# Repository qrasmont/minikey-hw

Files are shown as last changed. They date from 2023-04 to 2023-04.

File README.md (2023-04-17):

# Minikey

Mini is a macropad.

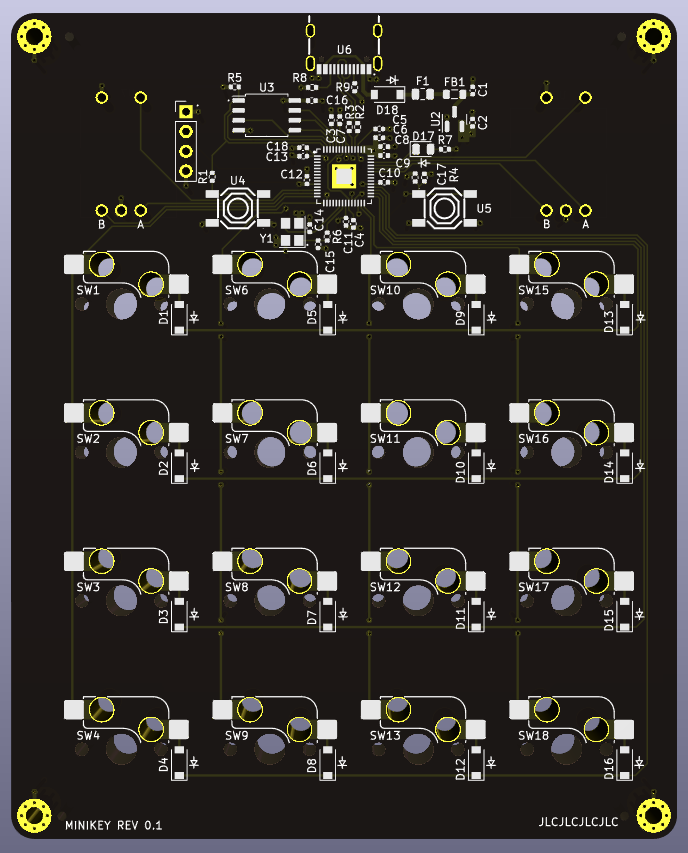
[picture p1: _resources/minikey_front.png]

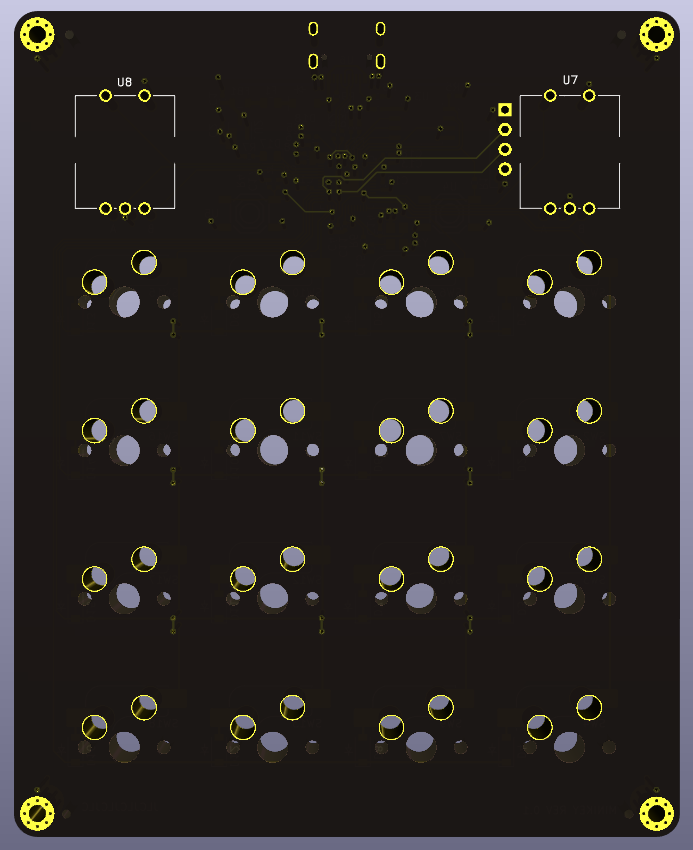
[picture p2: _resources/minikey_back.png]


## Rev 0.1




### Rev 0.1 Issues

Only related to the BOM.
- Button were not assembled
- R2,R3 are 27K instead of 27 Ohm.

# Characteristics

- 2 rotatry encoders
- 16 keys (Cherry MX, hot swappable)
- USB-C
- RP2040 MCU

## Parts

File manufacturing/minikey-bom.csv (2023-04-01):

Comment | Designator | Footprint | LCSC Part #
1u Unpolarized capacitor, small symbol | C1,C2,C5,C6 | C_0402_1005Metric | C52923
100n Unpolarized capacitor, small symbol | C3,C4,C7,C8,C9,C10,C11,C12,C13,C16,C17,C18 | C_0402_1005Metric | C307331
30p Unpolarized capacitor, small symbol | C14,C15 | C_0402_1005Metric | C1570
D Diode | D1,D2,D3,D4,D5,D6,D7,D8,D9,D10,D11,D12,D13,D14,D15,D16 | D_SOD-123 | C81598
LED Light emitting diode | D17 | LED_0805_2012Metric | C2297
B5819W SL 40V 600mV@1A 1A SOD-323 Schottky Barrier Diodes, SOD-323 | D18 | D_SOD-123 | C8598
TLC-PSMD050 Resettable fuse, polymeric positive temperature coefficient, small symbol | F1 | Fuse_0805_2012Metric | C261942
100@100MHz Ferrite bead, small symbol | FB1 | L_0805_2012Metric | C1015
1k Resistor, small symbol | R1,R6 | R_0402_1005Metric | C11702
27 Resistor, small symbol | R2,R3 | R_0402_1005Metric | C25771
10k Resistor, small symbol | R4,R5 | R_0402_1005Metric | C25744
1k5 Resistor, small symbol | R7 | R_0402_1005Metric | C25867
5k1 Resistor, small symbol | R8,R9 | R_0402_1005Metric | C25905
RP2040TR7 | U1 | QFN40P700X700X90-57N | C2040
XC6206PxxxMR Positive 60-250mA Low Dropout Regulator, Fixed Output, SOT-23 | U2 | SOT-23 | C5446
W25Q128JVS 128Mb Serial Flash Memory, Standard/Dual/Quad SPI, SOIC-8 | U3 | SOIC-8_5.23x5.23mm_P1.27mm | C97521
BOOT | U4 | tactile-switch | C318884
RESET | U5 | tactile-switch | C318884
TYPE-C-31-M-12 | U6 | simple-usb-c | C165948
PEC11R-4215F-S0024 | U7,U8 | PEC11R-4215F-S0024
12MHz Four pin crystal, GND on pins 2 and 4 | Y1 | Crystal_SMD_3225-4Pin_3.2x2.5mm | C9002

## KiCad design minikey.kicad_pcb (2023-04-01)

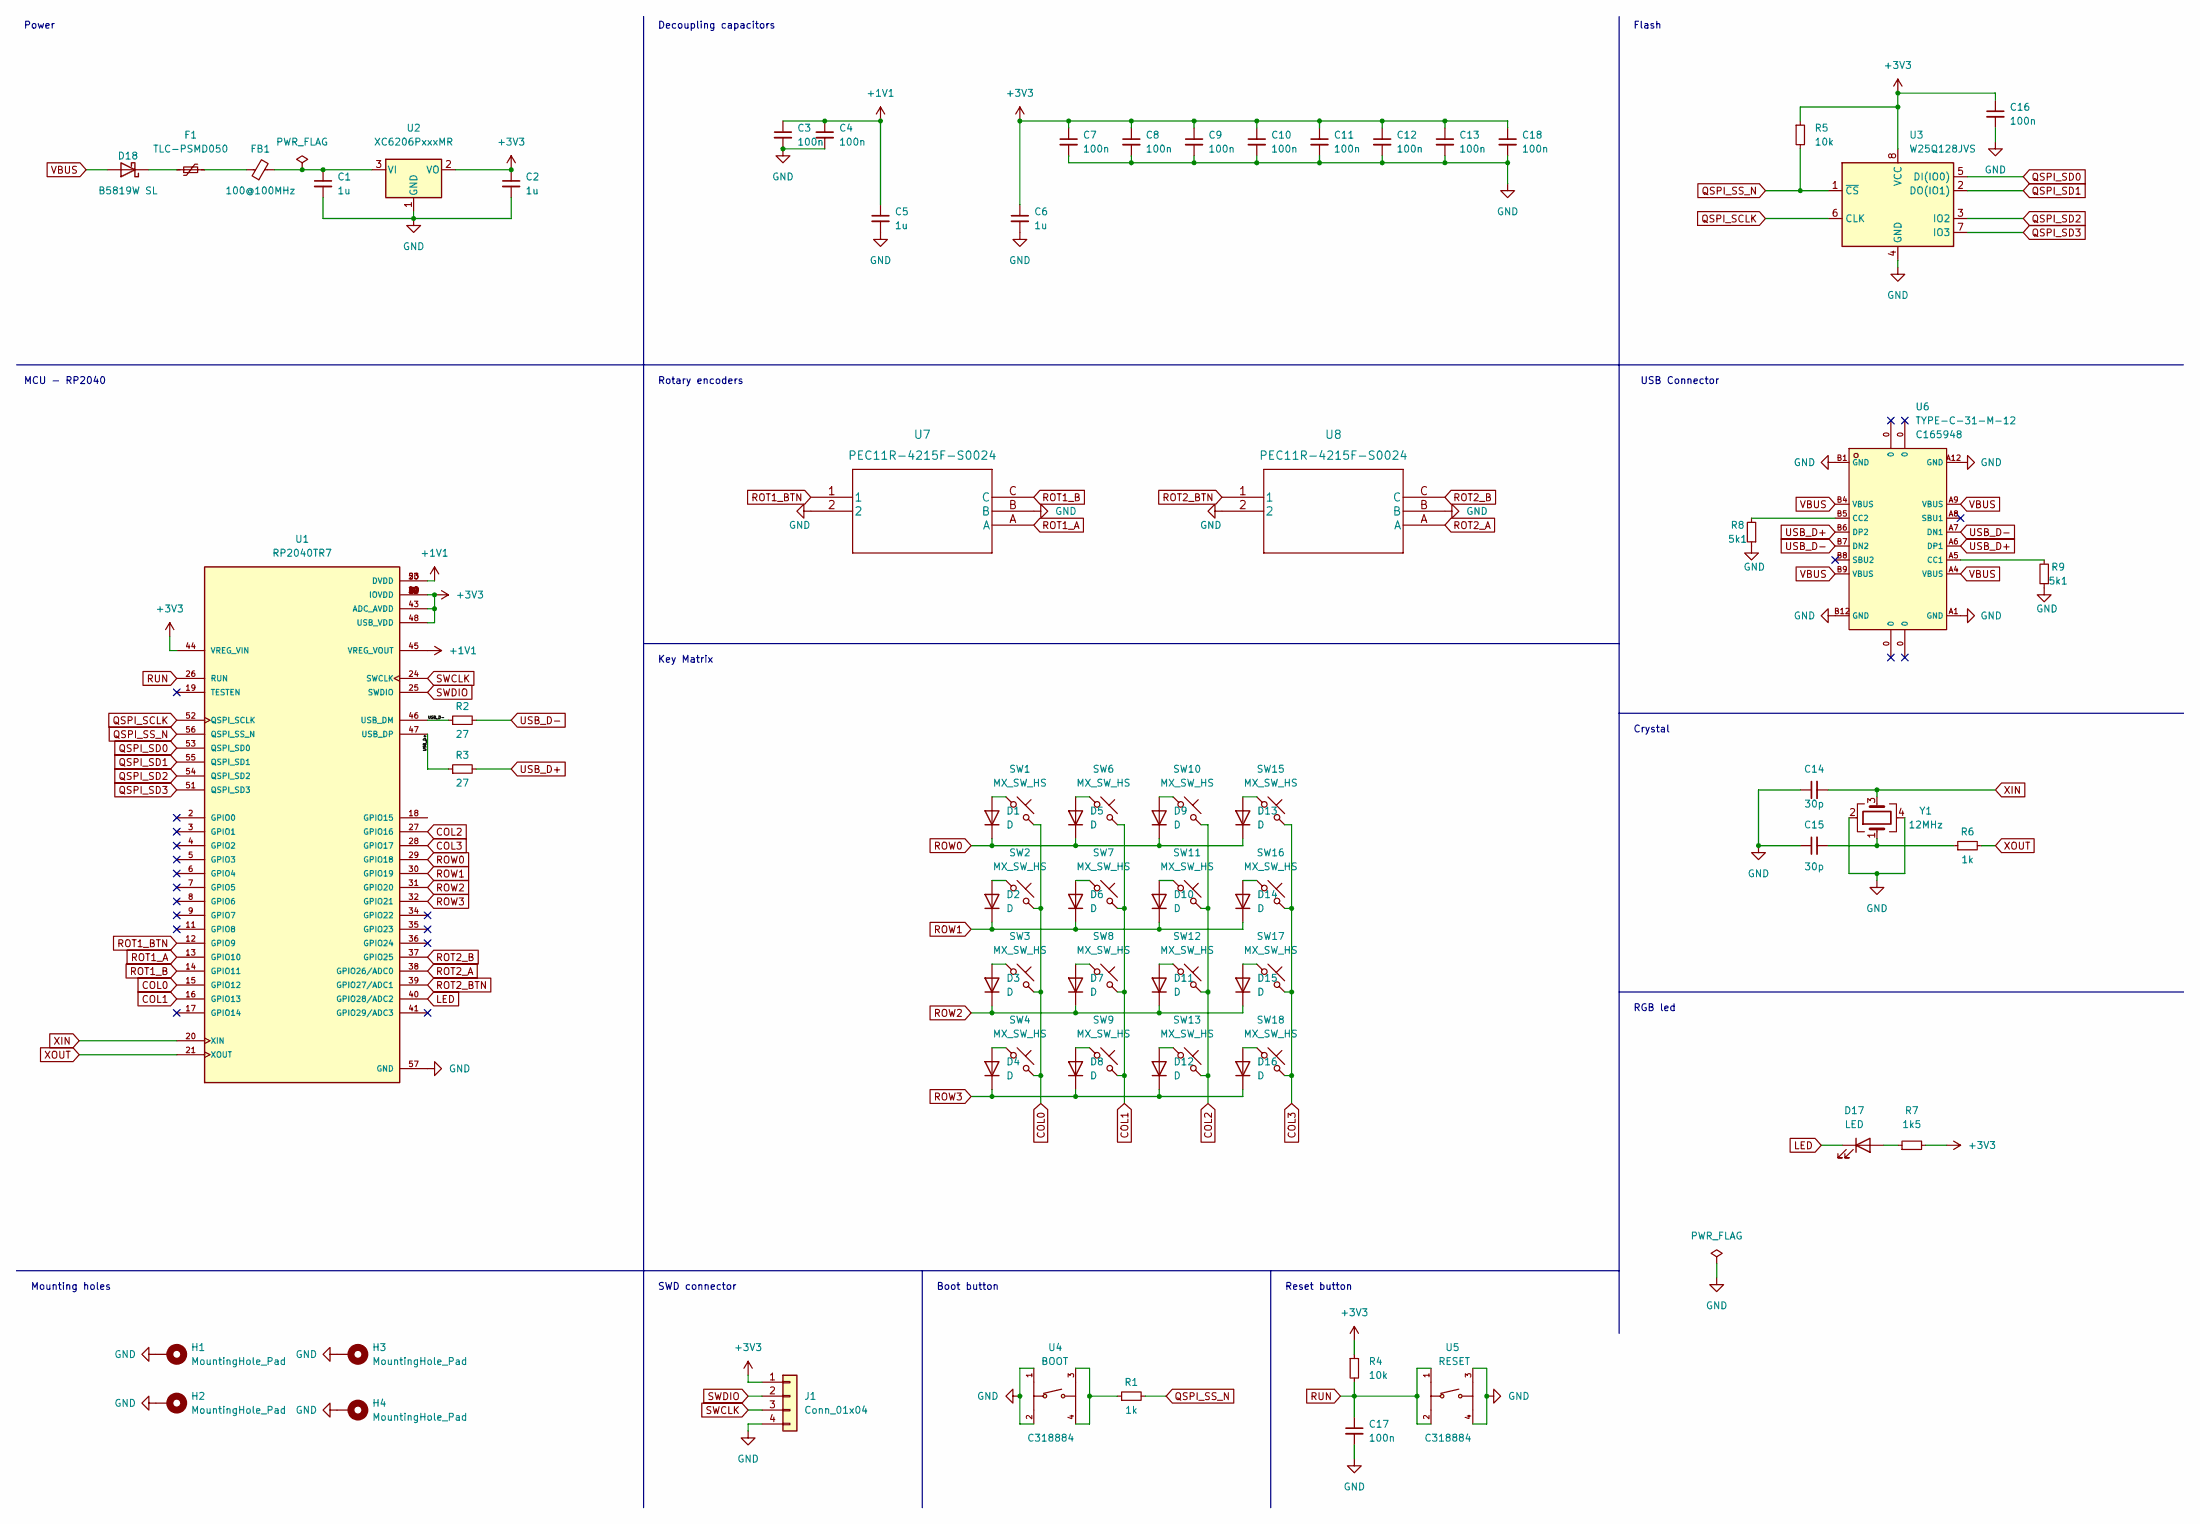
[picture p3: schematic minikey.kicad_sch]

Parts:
C1, C2, C5, C6: 1u; C_0402_1005Metric; LCSC Part # C52923
C3, C4, C7, C8, C9, C10, C11, C12, C13, C16, C17, C18: 100n; C_0402_1005Metric; LCSC Part # C307331
C14, C15: 30p; C_0402_1005Metric; LCSC Part # C1570
D1, D2, D3, D4, D5, D6, D7, D8, D9, D10, D11, D12, D13, D14, D15, D16: D; D_SOD-123; LCSC Part # C81598
D17: LED; LED_0805_2012Metric; LCSC Part # C2297
D18: B5819W SL; D_SOD-123; LCSC Part # C8598
F1: TLC-PSMD050; Fuse_0805_2012Metric; LCSC Part # C261942
FB1: 100@100MHz; L_0805_2012Metric; LCSC Part # C1015
H1, H2, H3, H4: MountingHole_Pad; MountingHole_2.2mm_M2_Pad_Via
J1: Conn_01x04; PinHeader_1x04_P2.54mm_Vertical
R1, R6: 1k; R_0402_1005Metric; LCSC Part # C11702
R2, R3: 27; R_0402_1005Metric; LCSC Part # C25190
R4, R5: 10k; R_0402_1005Metric; LCSC Part # C25744
R7: 1k5; R_0402_1005Metric; LCSC Part # C25867
R8, R9: 5k1; R_0402_1005Metric; LCSC Part # C25905
SW1, SW2, SW3, SW4, SW6, SW7, SW8, SW9, SW10, SW11, SW12, SW13, SW15, SW16, SW17, SW18: MX_SW_HS; SW_MX_HS_1u
U1: RP2040TR7; QFN40P700X700X90-57N; PARTREV 1.7.1; LCSC Part # C2040
U2: XC6206PxxxMR; SOT-23; LCSC Part # C5446
U3: W25Q128JVS; SOIC-8_5.23x5.23mm_P1.27mm; LCSC Part # C97521
U4: BOOT; tactile-switch; LCSC C318884
U5: RESET; tactile-switch; LCSC C318884
U6: TYPE-C-31-M-12; simple-usb-c; LCSC C165948
U7, U8: PEC11R-4215F-S0024
Y1: 12MHz; Crystal_SMD_3225-4Pin_3.2x2.5mm; LCSC Part # C9002

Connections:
+1V1: C3.1, C4.1, C5.1, U1.23 (DVDD), U1.45 (VREG_VOUT), U1.50 (DVDD)
+3V3: C2.1, C6.1, C7.1, C8.1, C9.1, C10.1, C11.1, C12.1, C13.1, C16.1, C18.1, J1.1, R4.1, R5.1, R7.2, U1.1 (IOVDD), U1.10 (IOVDD), U1.22 (IOVDD), U1.33 (IOVDD), U1.42 (IOVDD), U1.43 (ADC_AVDD), U1.44 (VREG_VIN), U1.48 (USB_VDD), U1.49 (IOVDD), U2.2 (VO), U3.8 (VCC)
COL0: SW1.2, SW2.2, SW3.2, SW4.2, U1.15 (GPIO12)
COL1: SW6.2, SW7.2, SW8.2, SW9.2, U1.16 (GPIO13)
COL2: SW10.2, SW11.2, SW12.2, SW13.2, U1.27 (GPIO16)
COL3: SW15.2, SW16.2, SW17.2, SW18.2, U1.28 (GPIO17)
GND: C1.2, C2.2, C3.2, C4.2, C5.2, C6.2, C7.2, C8.2, C9.2, C10.2, C11.2, C12.2, C13.2, C14.1, C15.1, C16.2, C17.2, C18.2, H1.1, H2.1, H3.1, H4.1, J1.4, R8.1, R9.1, U1.57 (GND), U2.1 (GND), U3.4 (GND), U4.1 (A), U4.2 (B), U5.3 (C), U5.4 (D), U6.A1 (GND), U6.A12 (GND), U6.B1 (GND), U6.B12 (GND), U7.2, U7.B, U8.2, U8.B, Y1.2, Y1.4
LED: D17.1 (K), U1.40 (GPIO28/ADC2)
unnamed: C1.1, FB1.2, U2.3 (VI)
unnamed: C15.2, R6.1, Y1.1
unnamed: D1.2 (A), SW1.1
unnamed: D2.2 (A), SW2.1
unnamed: D3.2 (A), SW3.1
unnamed: D4.2 (A), SW4.1
unnamed: D5.2 (A), SW6.1
unnamed: D6.2 (A), SW7.1
unnamed: D7.2 (A), SW8.1
unnamed: D8.2 (A), SW9.1
unnamed: D9.2 (A), SW10.1
unnamed: D10.2 (A), SW11.1
unnamed: D11.2 (A), SW12.1
unnamed: D12.2 (A), SW13.1
unnamed: D13.2 (A), SW15.1
unnamed: D14.2 (A), SW16.1
unnamed: D15.2 (A), SW17.1
unnamed: D16.2 (A), SW18.1
unnamed: D17.2 (A), R7.1
unnamed: D18.1 (K), F1.1
unnamed: F1.2, FB1.1
unnamed: R1.1, U4.3 (C), U4.4 (D)
unnamed: R8.2, U6.B5 (CC2)
unnamed: R9.2, U6.A5 (CC1)
QSPI_SCLK: U1.52 (QSPI_SCLK), U3.6 (CLK)
QSPI_SD0: U1.53 (QSPI_SD0), U3.5 (DI(IO0))
QSPI_SD1: U1.55 (QSPI_SD1), U3.2 (DO(IO1))
QSPI_SD2: U1.54 (QSPI_SD2), U3.3 (IO2)
QSPI_SD3: U1.51 (QSPI_SD3), U3.7 (IO3)
QSPI_SS_N: R1.2, R5.2, U1.56 (QSPI_SS_N), U3.1 (~CS)
ROT1_A: U1.13 (GPIO10), U7.A
ROT1_B: U1.14 (GPIO11), U7.C
ROT1_BTN: U1.12 (GPIO9), U7.1
ROT2_A: U1.38 (GPIO26/ADC0), U8.A
ROT2_B: U1.37 (GPIO25), U8.C
ROT2_BTN: U1.39 (GPIO27/ADC1), U8.1
ROW0: D1.1 (K), D5.1 (K), D9.1 (K), D13.1 (K), U1.29 (GPIO18)
ROW1: D2.1 (K), D6.1 (K), D10.1 (K), D14.1 (K), U1.30 (GPIO19)
ROW2: D3.1 (K), D7.1 (K), D11.1 (K), D15.1 (K), U1.31 (GPIO20)
ROW3: D4.1 (K), D8.1 (K), D12.1 (K), D16.1 (K), U1.32 (GPIO21)
RUN: C17.1, R4.2, U1.26 (RUN), U5.1 (A), U5.2 (B)
SWCLK: J1.3, U1.24 (SWCLK)
SWDIO: J1.2, U1.25 (SWDIO)
USB_D+: R3.1, R3.2, U1.47 (USB_DP), U6.A6 (DP1), U6.B6 (DP2)
USB_D-: R2.1, R2.2, U1.46 (USB_DM), U6.A7 (DN1), U6.B7 (DN2)
VBUS: D18.2 (A), U6.A4 (VBUS), U6.A9 (VBUS), U6.B4 (VBUS), U6.B9 (VBUS)
XIN: C14.2, U1.20 (XIN), Y1.3
XOUT: R6.2, U1.21 (XOUT)

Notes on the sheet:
Reset button
Mounting holes
Decoupling capacitors
Power
USB Connector
Rotary encoders
Flash
Crystal
SWD connector
RGB led
Key Matrix
MCU - RP2040
Boot button

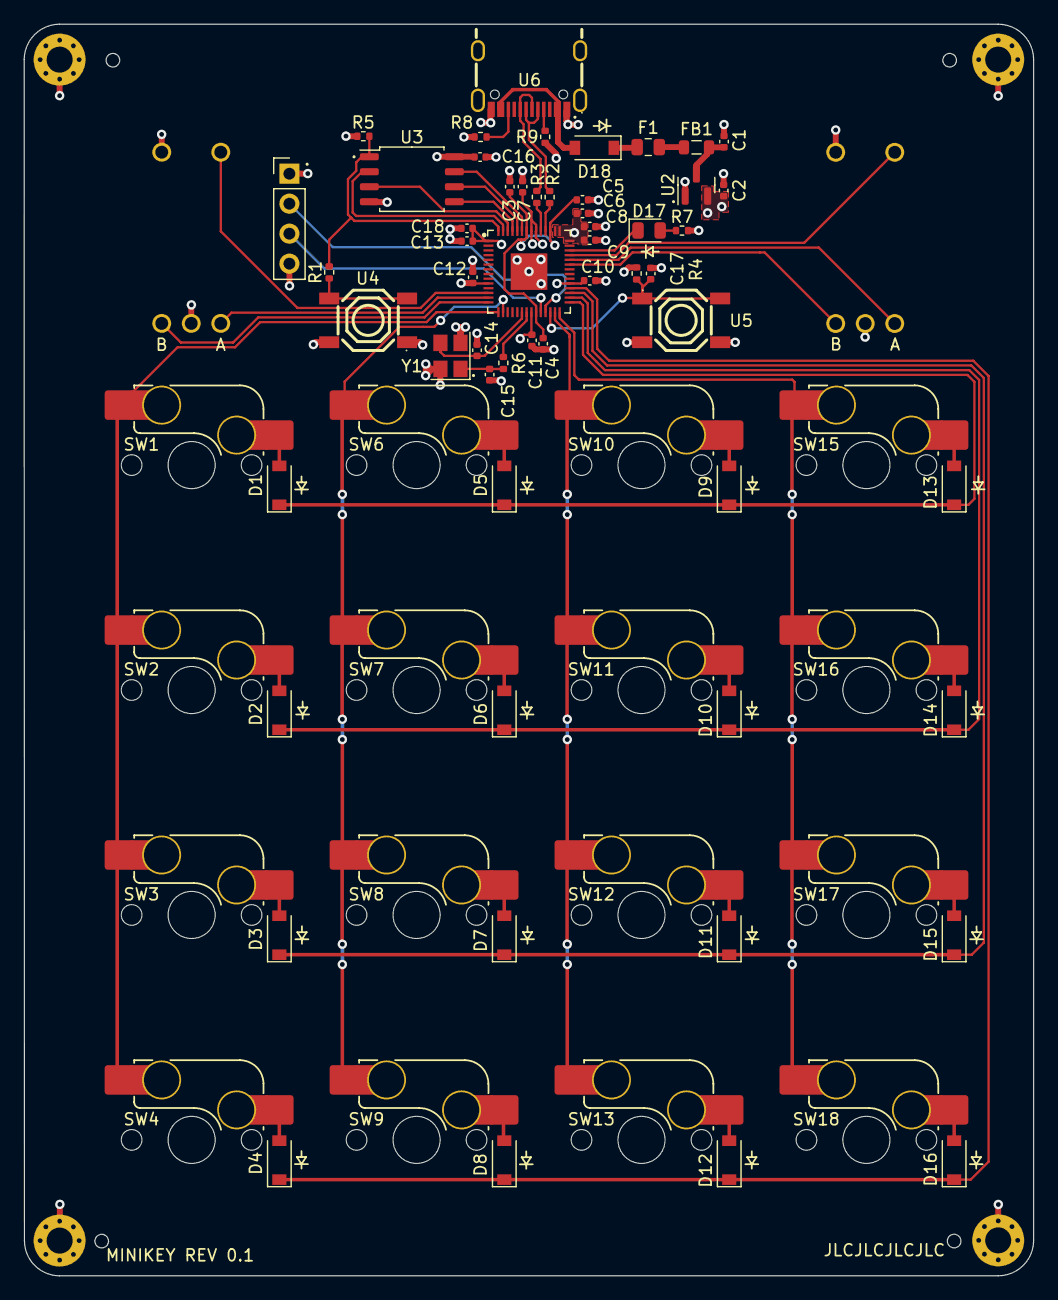
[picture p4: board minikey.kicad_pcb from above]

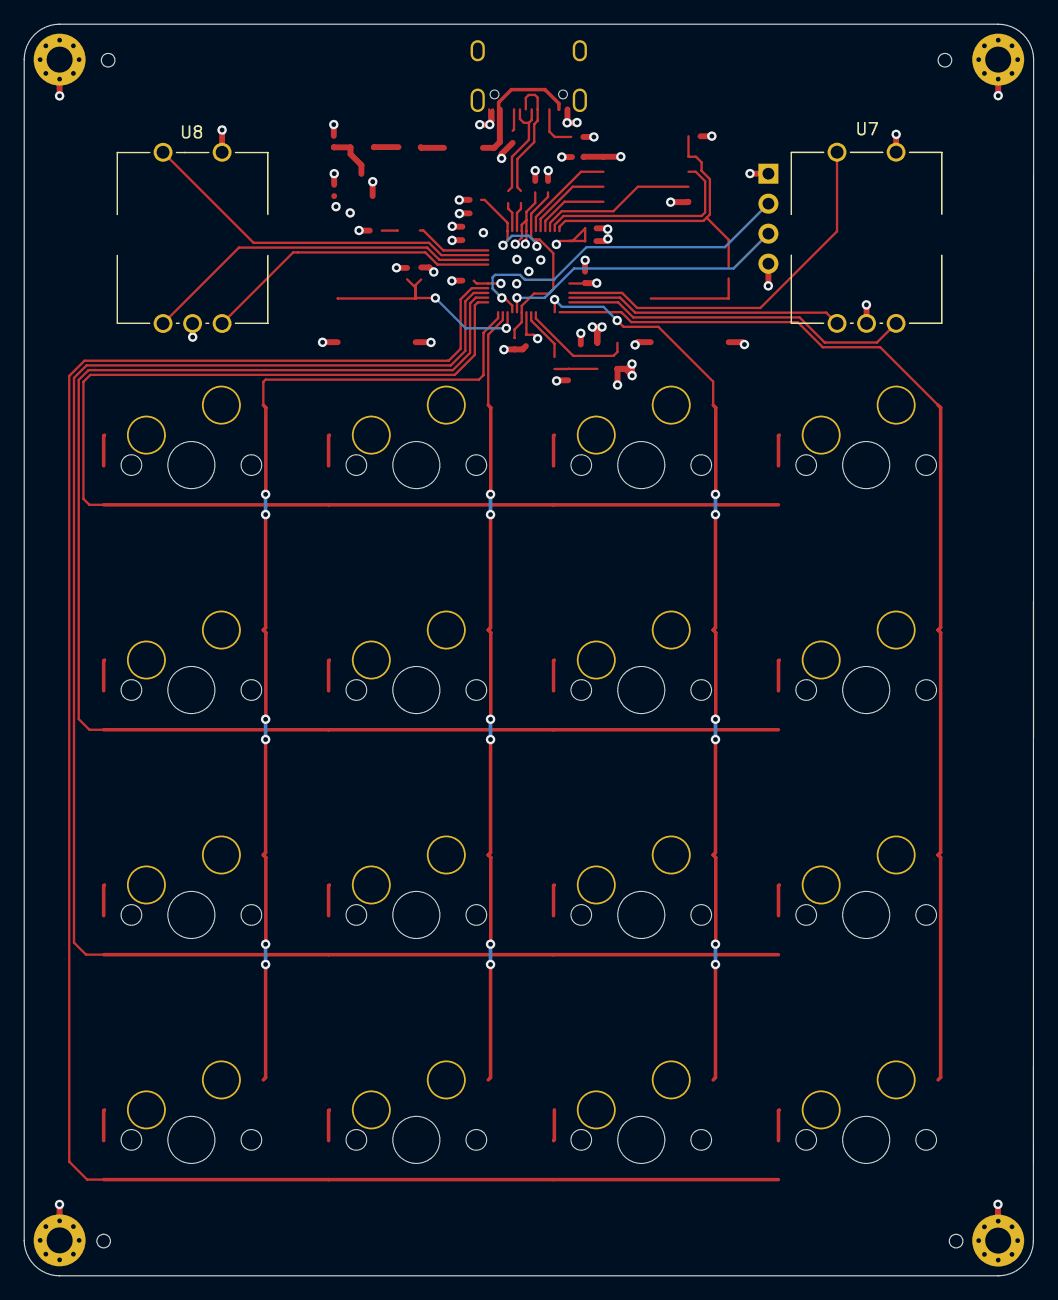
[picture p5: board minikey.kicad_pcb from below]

Board: 4 copper layers, 85.5 x 106.0 mm, 77 parts (2 on the bottom side), 56 nets.

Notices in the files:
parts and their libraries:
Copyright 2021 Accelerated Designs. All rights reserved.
